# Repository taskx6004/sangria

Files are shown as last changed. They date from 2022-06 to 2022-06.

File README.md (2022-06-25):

# sangria
Raspberry Pi Zero based handheld computer

It's basically a TI's USB 1s lithium battery charger to provide both buck and boost switching functions, to simplify the power design. The LCD is connected default SPI arrangement (SPI0), and keyboard is a USB HID device to provide user input.

## Initial commit
This version has a working keyboard based on BBQ10 with RP2040 by running modified version firmware from https://github.com/solderparty/i2c_puppet

### Known Issues:
- BQ25616 needs OTG pin strobe to GND to initialized battery charge, as this pin has already pulled high, thus to boost battery voltage to 5V.
- USB traces are inverted, the symbol for RPI part has the pin number inverted, thus a PCB trace rework is required.
- BQ25616 can pull 7.5v from some high power USB charger, Pi Zero power IC will emit the magic smoke in minutes...
- Keyboard LED MOSFET gate pin is not connected.

### What's next
- Add a USB hub chip to hook more RP2040 with B2B connector to house peripherals
- Add a nrf52840 to house Meshtastic device, with small OLED and GPS
- Replace BQ25616 and drop a DC/DC to PMID output, to prevent fry your Pi Zero, and you can hook a 4s model lithium battery pack
- Add a jog dial to keyboard chip, to implement tab/up arrow/down arrow key, as command line auto completion and history function

## How to build firmware
Refer to i2c-puppet building guide. As pico SDK is included in the repo, git pull will consume 900M traffic, you have been warned. After pulling the repo, replace files in `app` folder, and add new file in `boards` directory. cmake command is changed to:

`cmake -DPICO_BOARD=bbq10kbd_breakout -DCMAKE_BUILD_TYPE=Debug ..`

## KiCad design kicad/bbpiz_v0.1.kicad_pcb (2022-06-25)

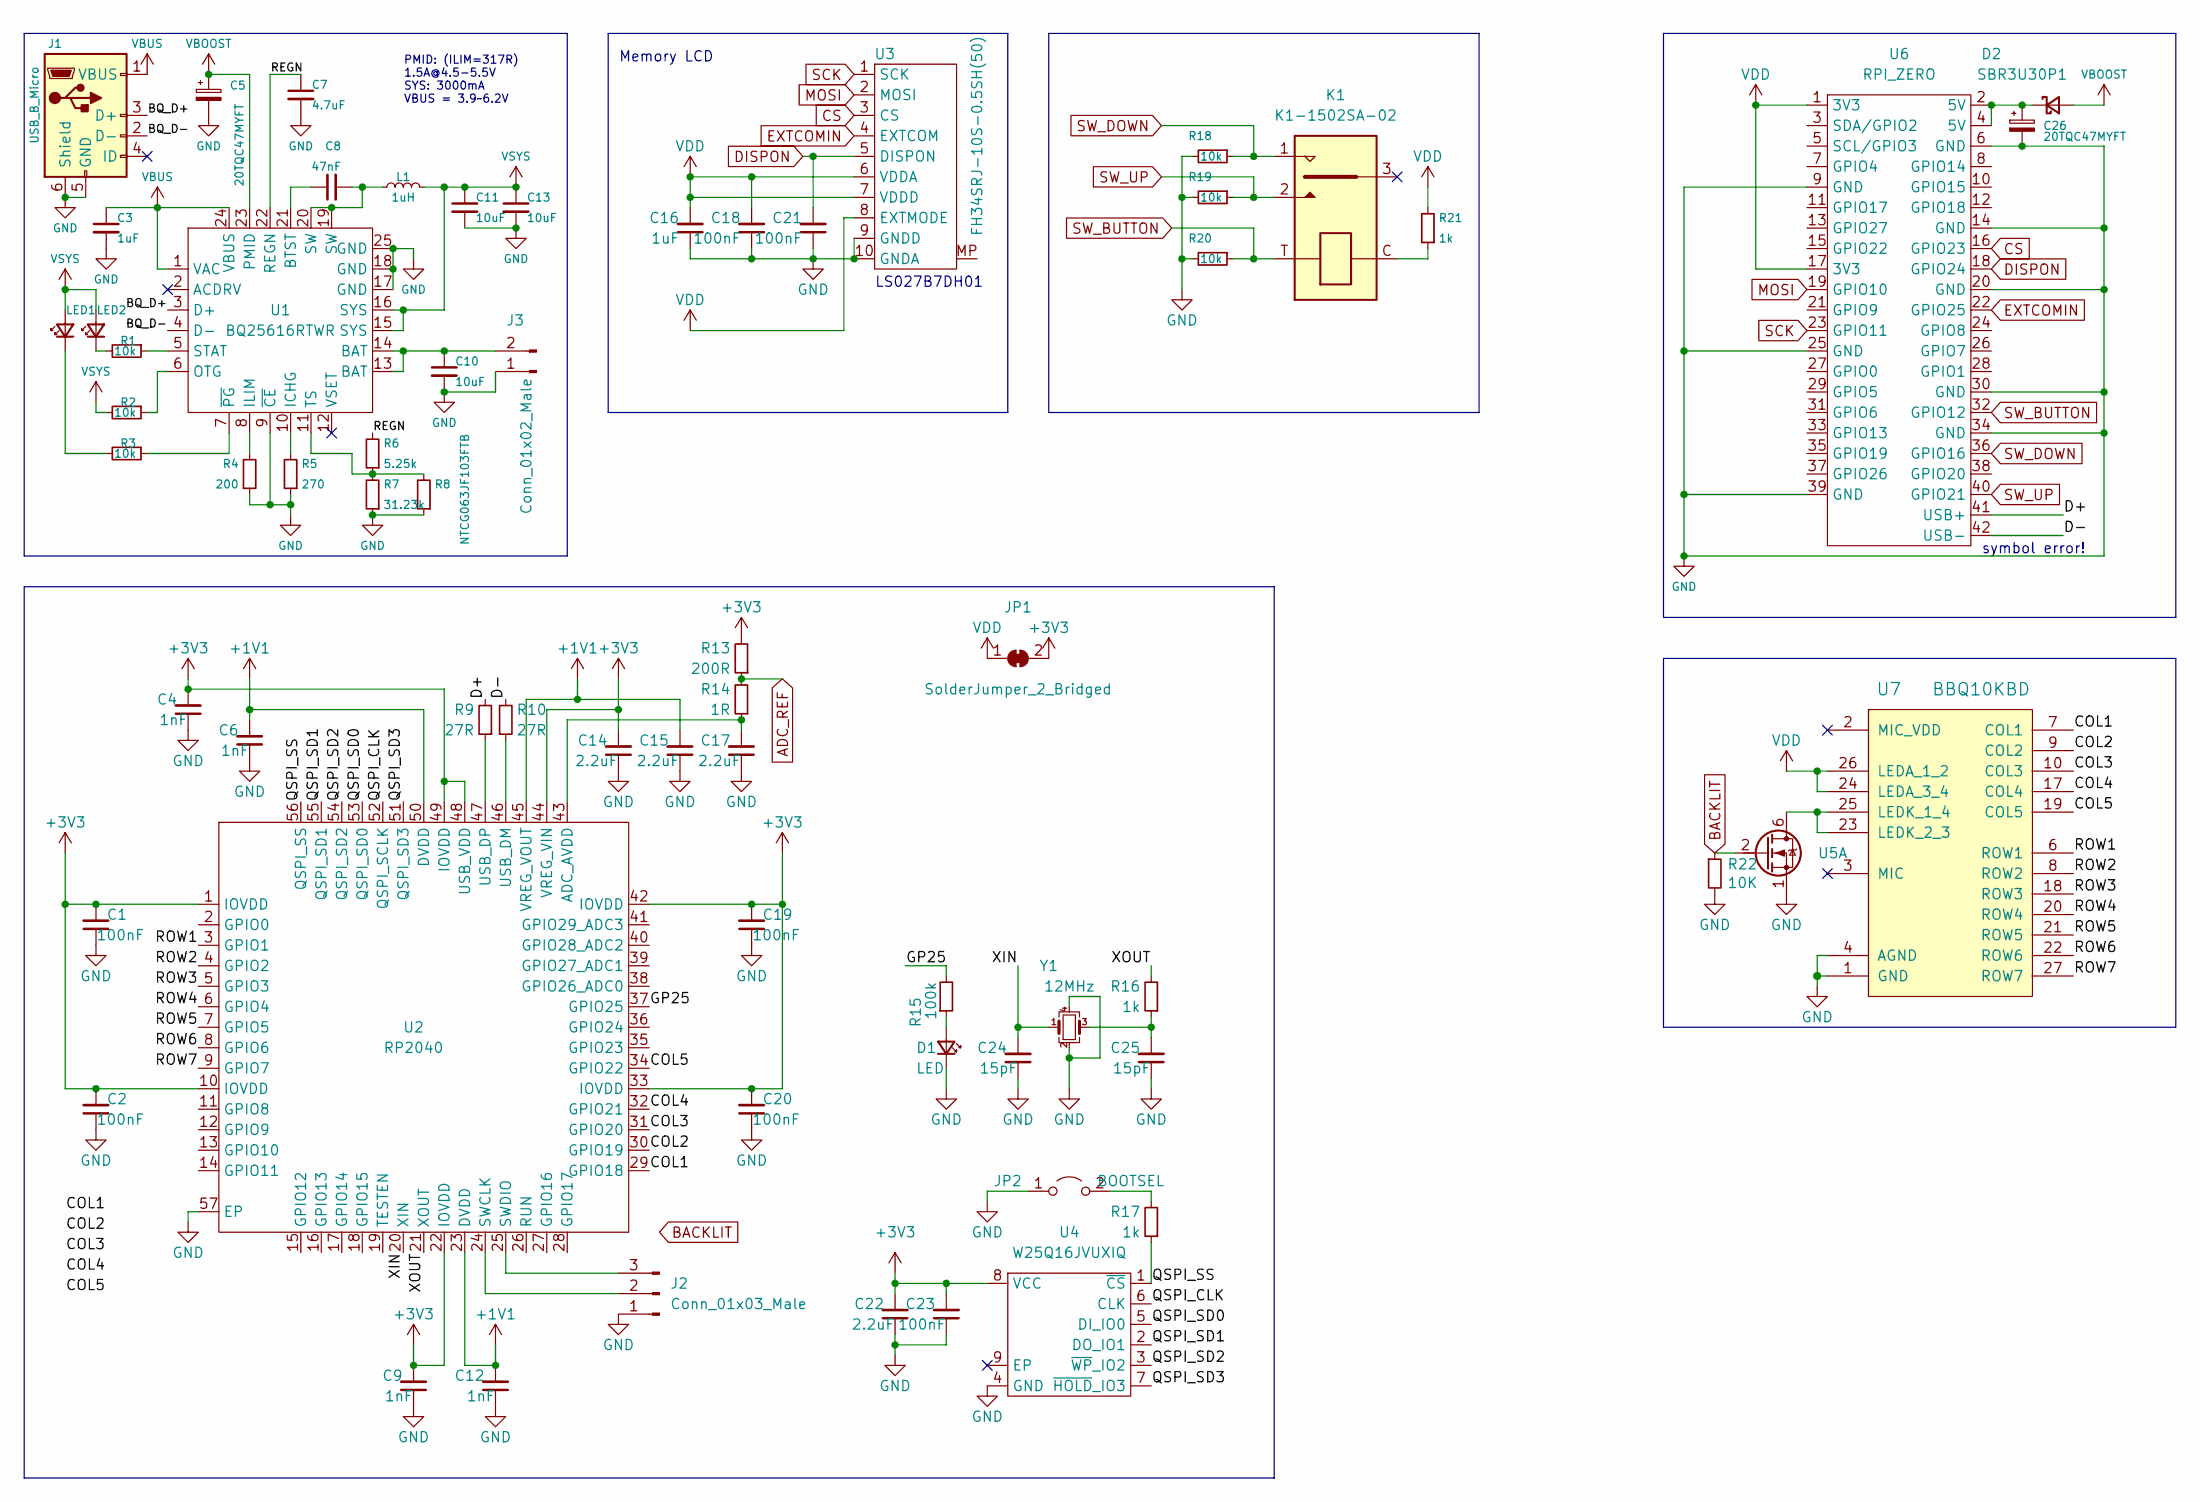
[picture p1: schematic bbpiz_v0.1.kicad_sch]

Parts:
C1, C2, C18, C19, C20, C21, C23: 100nF; C_0201_0603Metric
C3: 1uF; C_0603_1608Metric
C4, C6, C9, C12: 1nF; C_0201_0603Metric
C5, C26: 20TQC47MYFT
C7: 4.7uF; C_0402_1005Metric
C8: 47nF; C_0402_1005Metric
C10, C11, C13: 10uF; C_0603_1608Metric
C14, C15, C17, C22: 2.2uF; C_0402_1005Metric
C16: 1uF; C_0402_1005Metric
C24, C25: 15pF; C_0201_0603Metric
D1: LED; LED_0603_1608Metric
D2: SBR3U30P1; D_PowerDI-123
J1: USB_B_Micro; 474910001
J2: Conn_01x03_Male; PinHeader_1x03_P1.27mm_Vertical
J3: Conn_01x02_Male; HJX522365
JP1: SolderJumper_2_Bridged; SolderJumper-2_P1.3mm_Bridged_RoundedPad1.0x1.5mm
JP2: BOOTSEL; SolderJumper-2_P1.3mm_Open_RoundedPad1.0x1.5mm
K1: K1-1502SA-02
L1: 1uH; WIP252010P-1R0ML
LED1: LED; LED_0603_1608Metric
LED2: LED_RED_0603; LED_0603_1608Metric
R1, R2, R3, R18, R19, R20: 10k; R_0201_0603Metric
R4: 200; R_0201_0603Metric
R5: 270; R_0201_0603Metric
R6: 5.25k; R_0201_0603Metric
R7: 31.23k; R_0201_0603Metric
R8: NTCG063JF103FTB; R_0201_0603Metric
R9, R10: 27R; R_0201_0603Metric
R13: 200R; R_0201_0603Metric
R14: 1R; R_0201_0603Metric
R15: 100k; R_0201_0603Metric
R16, R17, R21: 1k; R_0201_0603Metric
R22: 10K; R_0201_0603Metric
U1: BQ25616RTWR; QFN-24-1EP_4x4mm_P0.5mm_EP2.7x2.7mm_ThermalVias
U2: RP2040
U3: FH34SRJ-10S-0.5SH(50)
U4: W25Q16JVUXIQ
U5: SIA517DJ-T1-GE3; Vishay_PowerPAK_SC70-6L_Dual
U6: RPI_ZERO; PI-ZERO_USB
U7: BBQ10KBD; BM14B(0.8)-24DS-0.4V(53)
Y1: 12MHz; Crystal_SMD_2520-4Pin_2.5x2.0mm

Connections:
+1V1: C6.2, C12.2, C15.2, U2.23 (DVDD), U2.45 (VREG_VOUT), U2.50 (DVDD)
+3V3: C1.2, C2.2, C4.2, C9.2, C14.2, C19.2, C20.2, C22.2, C23.2, JP1.2 (B), R13.2, U2.1 (IOVDD), U2.10 (IOVDD), U2.22 (IOVDD), U2.33 (IOVDD), U2.42 (IOVDD), U2.44 (VREG_VIN), U2.48 (USB_VDD), U2.49 (IOVDD), U4.8 (VCC)
/BQ_D+: J1.3 (D+), U1.3 (D+)
/BQ_D-: J1.2 (D-), U1.4 (D-)
/COL1: U2.29 (GPIO18), U7.7 (COL1)
/COL2: U2.30 (GPIO19), U7.9 (COL2)
/COL3: U2.31 (GPIO20), U7.10 (COL3)
/COL4: U2.32 (GPIO21), U7.17 (COL4)
/COL5: U2.34 (GPIO22), U7.19 (COL5)
/D+: R9.2, U6.41 (USB+)
/D-: R10.2, U6.42 (USB-)
/GP25: R15.2, U2.37 (GPIO25)
/QSPI_CLK: U2.52 (QSPI_SCLK), U4.6 (CLK)
/QSPI_SD0: U2.53 (QSPI_SD0), U4.5 (DI_IO0)
/QSPI_SD1: U2.55 (QSPI_SD1), U4.2 (DO_IO1)
/QSPI_SD2: U2.54 (QSPI_SD2), U4.3 (~WP_IO2)
/QSPI_SD3: U2.51 (QSPI_SD3), U4.7 (~HOLD_IO3)
/QSPI_SS: R17.1, U2.56 (QSPI_SS), U4.1 (~CS)
/REGN: C7.1, R6.2, U1.22 (REGN)
/ROW1: U2.3 (GPIO1), U7.6 (ROW1)
/ROW2: U2.4 (GPIO2), U7.8 (ROW2)
/ROW3: U2.5 (GPIO3), U7.18 (ROW3)
/ROW4: U2.6 (GPIO4), U7.20 (ROW4)
/ROW5: U2.7 (GPIO5), U7.21 (ROW5)
/ROW6: U2.8 (GPIO6), U7.22 (ROW6)
/ROW7: U2.9 (GPIO7), U7.27 (ROW7)
/XIN: C24.2, U2.20 (XIN), Y1.1
/XOUT: R16.2, U2.21 (XOUT)
ADC_REF: R13.1, R14.2
BACKLIT: R22.1, U5.2
CS: U3.3 (CS), U6.16 (GPIO23)
DISPON: C21.2, U3.5 (DISPON), U6.18 (GPIO24)
EXTCOMIN: U3.4 (EXTCOM), U6.22 (GPIO25)
GND: C1.1, C2.1, C3.2, C4.1, C5.2, C6.1, C7.2, C9.1, C10.2, C11.2, C12.1, C13.2, C14.1, C15.1, C16.1, C17.1, C18.1, C19.1, C20.1, C21.1, C22.1, C23.1, C24.1, C25.1, C26.2, D1.1 (K), J1.5 (GND), J1.6 (Shield), J2.1, J3.1, JP2.1 (A), R4.1, R5.1, R7.1, R8.1, R18.2, R19.2, R20.2, R22.2, U1.9 (~CE), U1.17 (GND), U1.18 (GND), U1.25 (GND), U2.57 (EP), U3.9 (GNDD), U3.10 (GNDA), U4.4 (GND), U5.1, U6.6 (GND), U6.9 (GND), U6.14 (GND), U6.20 (GND), U6.25 (GND), U6.30 (GND), U6.34 (GND), U6.39 (GND), U7.1 (GND), U7.4 (AGND), U7.5 (GND), U7.11 (GND), U7.12 (GND), U7.13 (GND), U7.14 (GND), U7.15 (GND), U7.16 (GND), U7.28 (GND), Y1.2, Y1.4
MOSI: U3.2 (MOSI), U6.19 (GPIO10)
unnamed: C8.1, U1.21 (BTST)
unnamed: C8.2, L1.1, U1.19 (SW), U1.20 (SW)
unnamed: C10.1, J3.2, U1.13 (BAT), U1.14 (BAT)
unnamed: C17.2, R14.1, U2.43 (ADC_AVDD)
unnamed: C25.2, R16.1, Y1.3
unnamed: C26.1, D2.1 (K), U6.2 (5V), U6.4 (5V)
unnamed: D1.2 (A), R15.1
unnamed: J2.2, U2.24 (SWCLK)
unnamed: J2.3, U2.25 (SWDIO)
unnamed: JP2.2 (B), R17.2
unnamed: K1.C, R21.1
unnamed: LED1.1 (K), R3.2
unnamed: LED2.1 (K), R1.2
unnamed: R1.1, U1.5 (STAT)
unnamed: R2.1, U1.6 (OTG)
unnamed: R3.1, U1.7 (~PG)
unnamed: R4.2, U1.8 (ILIM)
unnamed: R5.2, U1.10 (ICHG)
unnamed: R6.1, R7.2, R8.2, U1.11 (TS)
unnamed: R9.1, U2.47 (USB_DP)
unnamed: R10.1, U2.46 (USB_DM)
unnamed: U5.6, U7.23 (LEDK_2_3), U7.25 (LEDK_1_4)
SCK: U3.1 (SCK), U6.23 (GPIO11)
SW_BUTTON: K1.T, R20.1, U6.32 (GPIO12)
SW_DOWN: K1.1, R18.1, U6.36 (GPIO16)
SW_UP: K1.2, R19.1, U6.40 (GPIO21)
VBOOST: C5.1, D2.2 (A), U1.23 (PMID)
VBUS: C3.1, J1.1 (VBUS), U1.1 (VAC), U1.24 (VBUS)
VDD: C16.2, C18.2, JP1.1 (A), R21.2, U3.6 (VDDA), U3.7 (VDDD), U3.8 (EXTMODE), U6.1 (3V3), U6.17 (3V3), U7.24 (LEDA_3_4), U7.26 (LEDA_1_2)
VSYS: C11.1, C13.1, L1.2, LED1.2 (A), LED2.2 (A), R2.2, U1.15 (SYS), U1.16 (SYS)

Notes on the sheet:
symbol error!
LS027B7DH01
Memory LCD
PMID: (ILIM=317R) 1.5A@4.5-5.5V SYS: 3000mA VBUS = 3.9~6.2V

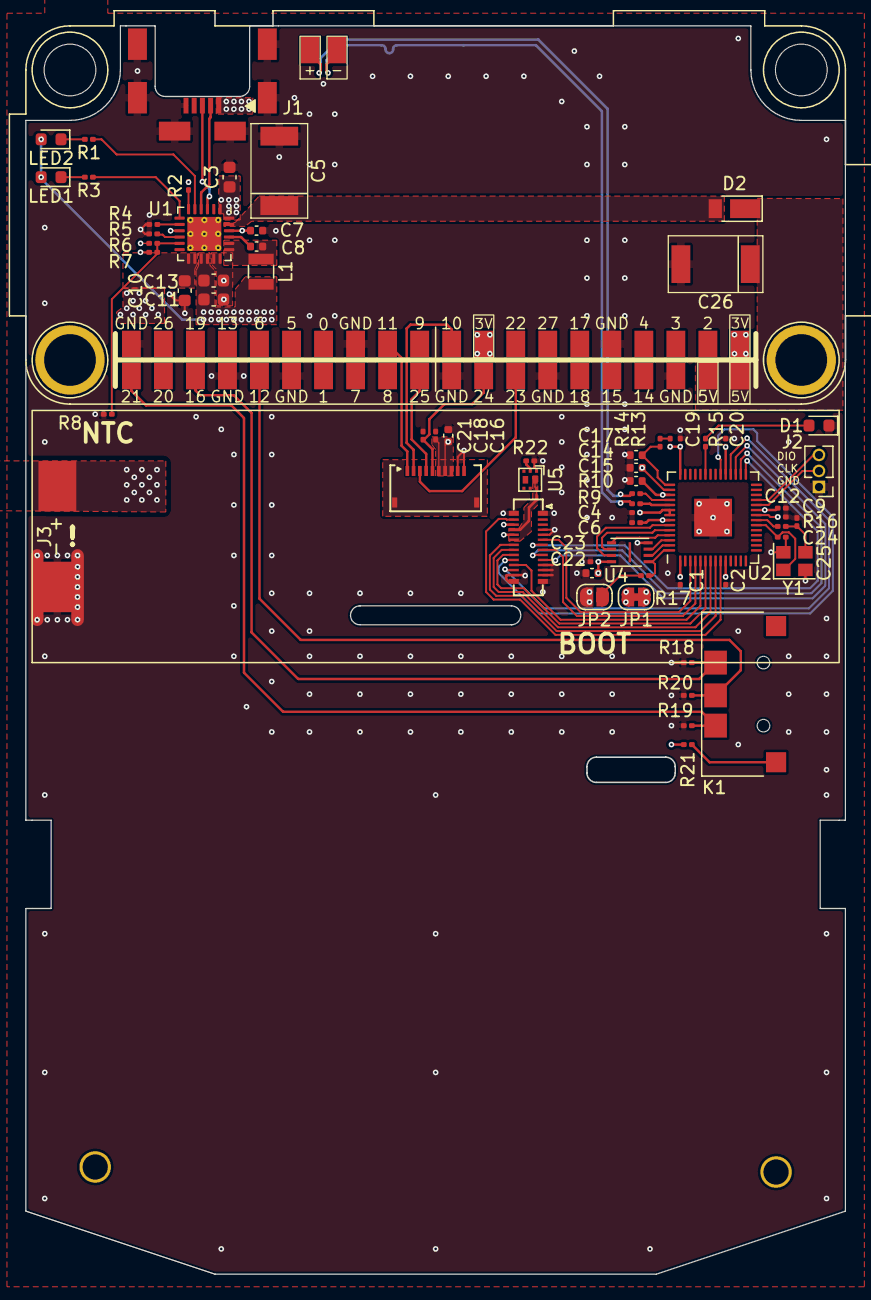
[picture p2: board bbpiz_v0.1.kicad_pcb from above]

Board: 4 copper layers, 65.0 x 99.0 mm, 65 parts (0 on the bottom side), 65 nets.

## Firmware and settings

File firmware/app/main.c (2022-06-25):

#include <pico/stdlib.h>
#include <stdio.h>
#include <tusb.h>

#include "backlight.h"
#include "debug.h"
#include "gpioexp.h"
#include "interrupt.h"
#include "keyboard.h"
#include "puppet_i2c.h"
#include "reg.h"
#include "touchpad.h"
#include "usb.h"

// since the SDK doesn't support per-GPIO irq, we use this global irq and forward it
static void gpio_irq(uint gpio, uint32_t events)
{
//	printf("%s: gpio %d, events 0x%02X\r\n", __func__, gpio, events);
	touchpad_gpio_irq(gpio, events);
	gpioexp_gpio_irq(gpio, events);
}

// TODO: Microphone
int main(void)
{
	// The here order is important because it determines callback call order
	usb_init();

#ifndef NDEBUG
	debug_init();
#endif

	reg_init();

	backlight_init();

	gpioexp_init();

	keyboard_init();

	//touchpad_init();

	interrupt_init();

	puppet_i2c_init();

	// For now, the `gpio` param is ignored and all enabled GPIOs generate the irq
	gpio_set_irq_enabled_with_callback(0xFF, 0, true, &gpio_irq);

#ifndef NDEBUG
	printf("Starting main loop\r\n");
#endif

	while (true) {
		__wfe();
	}

	return 0;
}

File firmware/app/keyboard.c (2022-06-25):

#include "app_config.h"
#include "fifo.h"
#include "keyboard.h"
#include "reg.h"

#include <pico/stdlib.h>

#define LIST_SIZE	10 // size of the list keeping track of all the pressed keys

struct entry
{
	char chr;
	char alt;
	enum key_mod mod;
};

struct list_item
{
	const struct entry *p_entry;
	uint32_t hold_start_time;
	enum key_state state;
	bool mods[KEY_MOD_ID_LAST];
	char effective_key;
};

static const uint8_t row_pins[NUM_OF_ROWS] =
{
	PINS_ROWS
};

static const uint8_t col_pins[NUM_OF_COLS] =
{
	PINS_COLS
};

#pragma GCC diagnostic push
#pragma GCC diagnostic ignored "-Wmissing-field-initializers"

static const struct entry kbd_entries[][NUM_OF_COLS] =
/* {
	{ { KEY_JOY_CENTER },  { 'W', '1' },              { 'G', '/' },              { 'S', '4' },              { 'L', '"'  },  { 'H' , ':' } },
	{ { },                 { 'Q', '#' },              { 'R', '3' },              { 'E', '2' },              { 'O', '+'  },  { 'U', '_'  } },
	{ { KEY_BTN_LEFT1 },   { '~', '0' },              { 'F', '6' },              { .mod = KEY_MOD_ID_SHL }, { 'K', '\''  }, { 'J', ';'  } },
	{ { },                 { ' ', '\t' },             { 'C', '9' },              { 'Z', '7' },              { 'M', '.'  },  { 'N', ','  } },
	{ { KEY_BTN_LEFT2 },   { .mod = KEY_MOD_ID_SYM }, { 'T', '(' },              { 'D', '5' },              { 'I', '-'  },  { 'Y', ')'  } },
	{ { KEY_BTN_RIGHT1 },  { .mod = KEY_MOD_ID_ALT }, { 'V', '?' },              { 'X', '8' },              { '$', '`'  },  { 'B', '!'  } },
	{ { },                 { 'A', '*' },              { .mod = KEY_MOD_ID_SHR }, { 'P', '@' },              { '\b' },       { '\n', '|' } },
}; */
{
	{ { 'Q', '#' },       { 'E', '2' },       { 'R', '3' },       { 'U', '_'  }, { 'O', '+'  } },
	{ { 'W', '1' },       { 'S', '4' },       { 'G', '/' },       { 'H', ':'  }, { 'L', '"'  } },
	{ { .mod = KEY_MOD_ID_SYM }, { 'D', '5' },       { 'T', '(' },       { 'Y', ')'  }, { 'I', '-'  } },
	{ { 'A', '*' },       { 'P', '@' },       { .mod = KEY_MOD_ID_SHR }, { '\n', '|' }, { '\b'      } },
	{ { .mod = KEY_MOD_ID_ALT }, { 'X', '8' },       { 'V', '?' },       { 'B', '!'  }, { '$', '`'  } },
	{ { ' ', '\t' },      { 'Z', '7' },       { 'C', '9' },       { 'N', ','  }, { 'M', '.'  } },
	{ { '~', '0' },       { .mod = KEY_MOD_ID_SHL }, { 'F', '6' },       { 'J', ';'  }, { 'K', '\'' } },
};

#if NUM_OF_BTNS > 0
static const struct entry btn_entries[NUM_OF_BTNS] =
{
	BTN_KEYS
};

static const uint8_t btn_pins[NUM_OF_BTNS] =
{
	PINS_BTNS
};
#endif

#pragma GCC diagnostic pop

static struct
{
	struct key_lock_callback *lock_callbacks;
	struct key_callback *key_callbacks;

	struct list_item list[LIST_SIZE];

	bool mods[KEY_MOD_ID_LAST];

	bool capslock_changed;
	bool capslock;

	bool numlock_changed;
	bool numlock;
} self;

static void transition_to(struct list_item * const p_item, const enum key_state next_state)
{
	const struct entry * const p_entry = p_item->p_entry;

	p_item->state = next_state;

	if (!p_entry)
		return;

	if (p_item->effective_key == '\0') {
		char key = p_entry->chr;
		switch (p_entry->mod) {
			case KEY_MOD_ID_ALT:
				if (reg_is_bit_set(REG_ID_CFG, CFG_REPORT_MODS))
					key = KEY_MOD_ALT;
				break;

			case KEY_MOD_ID_SHL:
				if (reg_is_bit_set(REG_ID_CFG, CFG_REPORT_MODS))
					key = KEY_MOD_SHL;
				break;

			case KEY_MOD_ID_SHR:
				if (reg_is_bit_set(REG_ID_CFG, CFG_REPORT_MODS))
					key = KEY_MOD_SHR;
				break;

			case KEY_MOD_ID_SYM:
				if (reg_is_bit_set(REG_ID_CFG, CFG_REPORT_MODS))
					key = KEY_MOD_SYM;
				break;

			default:
			{
				if (reg_is_bit_set(REG_ID_CFG, CFG_USE_MODS)) {
					const bool shift = (self.mods[KEY_MOD_ID_SHL] || self.mods[KEY_MOD_ID_SHR]) | self.capslock;
					const bool alt = self.mods[KEY_MOD_ID_ALT] | self.numlock;
					const bool is_button = (key <= KEY_BTN_RIGHT1) || ((key >= KEY_BTN_LEFT2) && (key <= KEY_BTN_RIGHT2));

					if (alt && !is_button) {
						key = p_entry->alt;
					} else if (!shift && (key >= 'A' && key <= 'Z')) {
						key = (key + ' ');
					}
				}

				break;
			}
		}

		p_item->effective_key = key;
	}

	if (p_item->effective_key == '\0')
		return;

	keyboard_inject_event(p_item->effective_key, next_state);
}
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
